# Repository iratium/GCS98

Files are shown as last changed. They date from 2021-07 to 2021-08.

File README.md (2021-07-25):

# GCS98
A collection of PCB and case designs for a modified 1800 layout I call GCS98.

modified_1800_v1_dark

I enjoy the flexibility of a full-size keyboard, but in my decade or so of using keyboards (including software for general home use, programming, gaming, and engineering work), I have never found a use for certain keys in and around the navigation cluster, namely Page Up, Page Down, Insert, Scroll Lock, Num Lock, and Pause Break. Additionally, the full size layout is not ergonomic in terms of gaming.

I discovered the 96% and 1800 layouts and felt I had discovered the perfect out-of-the-box solution in the 1800 layout specifically, but was disappointed to find that the layout is somewhat rare. My searches led me to the Keychron K4 (with this specific configuration https://www.keychron.com/products/keychron-k4-wireless-mechanical-keyboard-version-2?variant=32287344427097), and after substituting in Glorious Panda Switches for most keys and upgrading to PBT keys for the first time, I finally had a keyboard that felt like mine. Unfortunately, the K4 still has one major drawback being a compact 96% layout as opposed to a proper 1800: the remaining navigation keys, arrow keys, and delete key are not easily accessible by touch. 

To get the last 4% of customization that the compact 96% layout leaves in the aether, the only option forward is to do a fully custom build. I am a mechanical engineer by trade and I am familiar with the kinds of tools to design and manufacture a housed PCB; my specialty is not in electronics though, so I will inevitably be following tutorials and asking for help. 

Feel free to share this project with others, I've already been asked a couple of times whether I'd consider doing a group buy around this layout. You can also contact me over Discord Iratium#4718 or email at gavinshehan@gmail.com.

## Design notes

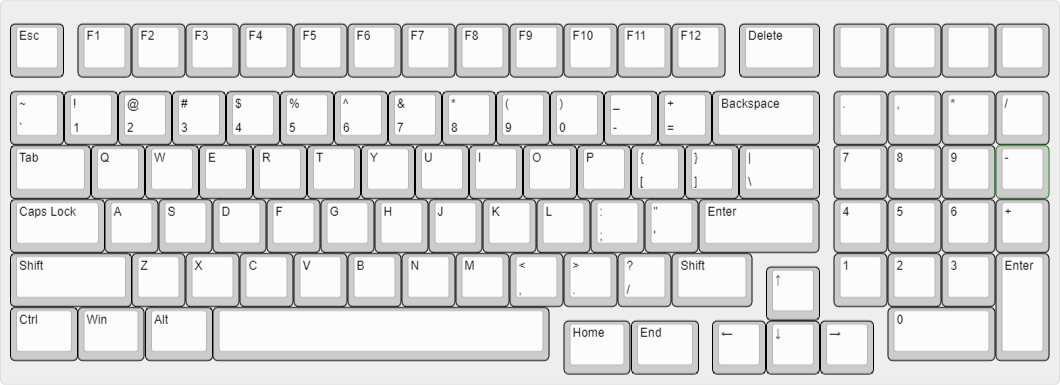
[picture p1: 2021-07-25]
GCS98.png

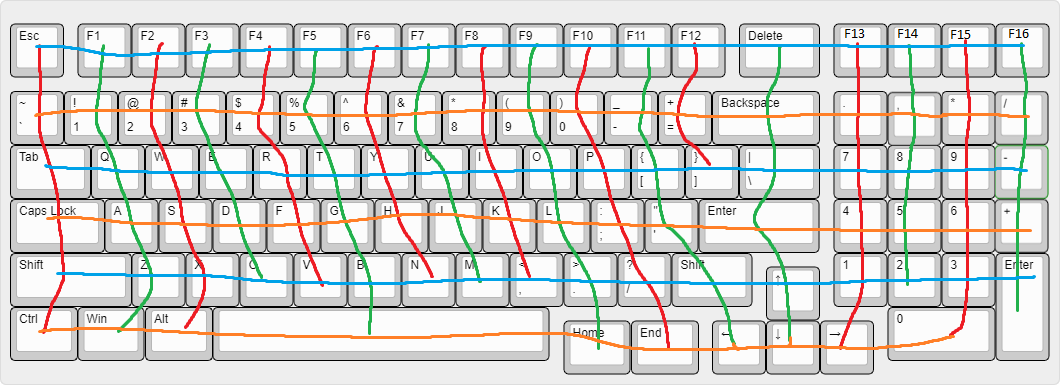
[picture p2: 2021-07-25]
GCS98 switch matrix.png

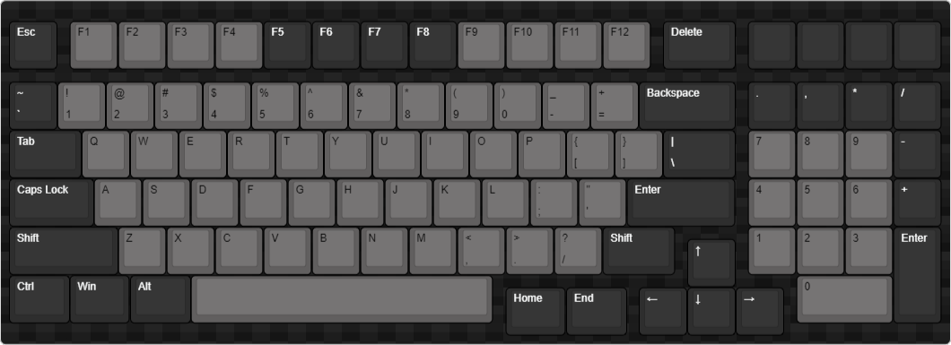
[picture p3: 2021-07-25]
GCS98_dark.png

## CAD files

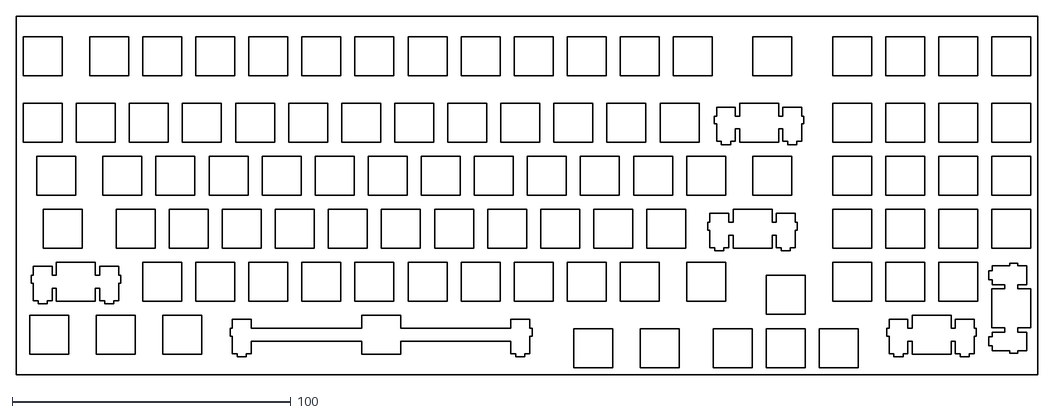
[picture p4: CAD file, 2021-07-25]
GCS98.dxf
366.7 x 128.6

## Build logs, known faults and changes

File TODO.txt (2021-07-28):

--------------------------------------------------------------------------------------
as of 2021-07-25:
--------------------------------------------------------------------------------------
GCS98v2
- find footprint for JST SH 4-pin connectors
- check to make sure it will work with the aio03-designed USB-C daughter board
- finalize outline of board to minimize space occupied outside of keycap footprint
- have someone verify board design for:
  * daughter board properly filters power rail/provides protection from ESD and other stuff
  * MCU is properly supplied with power and signal
  * MCU does actually have an internal oscillator and whether it will be sufficient
  * whether board has room for rgb to be added
  * overall design, whether it would function once assembled
        -> from here can fork off and work on v3 to add RGB
- start work toward midplate and case design:
  * manufacture (method and manufacturer)
  * materials
  * mounting method (gasket mounting ???)
  * modularity for loud/quiet versions (foam sheet, o-rings, rubber feet)
	
--------------------------------------------------------------------------------------
as of 2021-07-27:
--------------------------------------------------------------------------------------
GCS98v2
- check to make sure it will work with the aio03-designed USB-C daughter board
		= didn't verify 100% but it seems like it'll work
- finalize outline of board to minimize space occupied outside of keycap footprint
- have someone verify board design for:
		= should probably get a full design review before ordering parts if possible
  * daughter board properly filters power rail/provides protection from ESD and other stuff
		= pretty sure yea
  * MCU is properly supplied with power and signal
		= yup, but beware  pull-up resistor on D+
  * MCU does actually have an internal oscillator and whether it will be sufficient
		= internal resonator only for boot and low-speed operations, clock tends to vary
		widely with temperature; I am adding a crystal to the PCB
  * whether board has room for rgb to be added
		= yaes, check out sk6812 Mini-E RGB
  * overall design, whether it would function once assembled
        -> from here can fork off and work on v3 to add RGB
- start work toward midplate and case design:
  * manufacture (method and manufacturer)
  * materials
  * mounting method (gasket mounting ???)
  * modularity for loud/quiet versions (foam sheet, o-rings, rubber feet)

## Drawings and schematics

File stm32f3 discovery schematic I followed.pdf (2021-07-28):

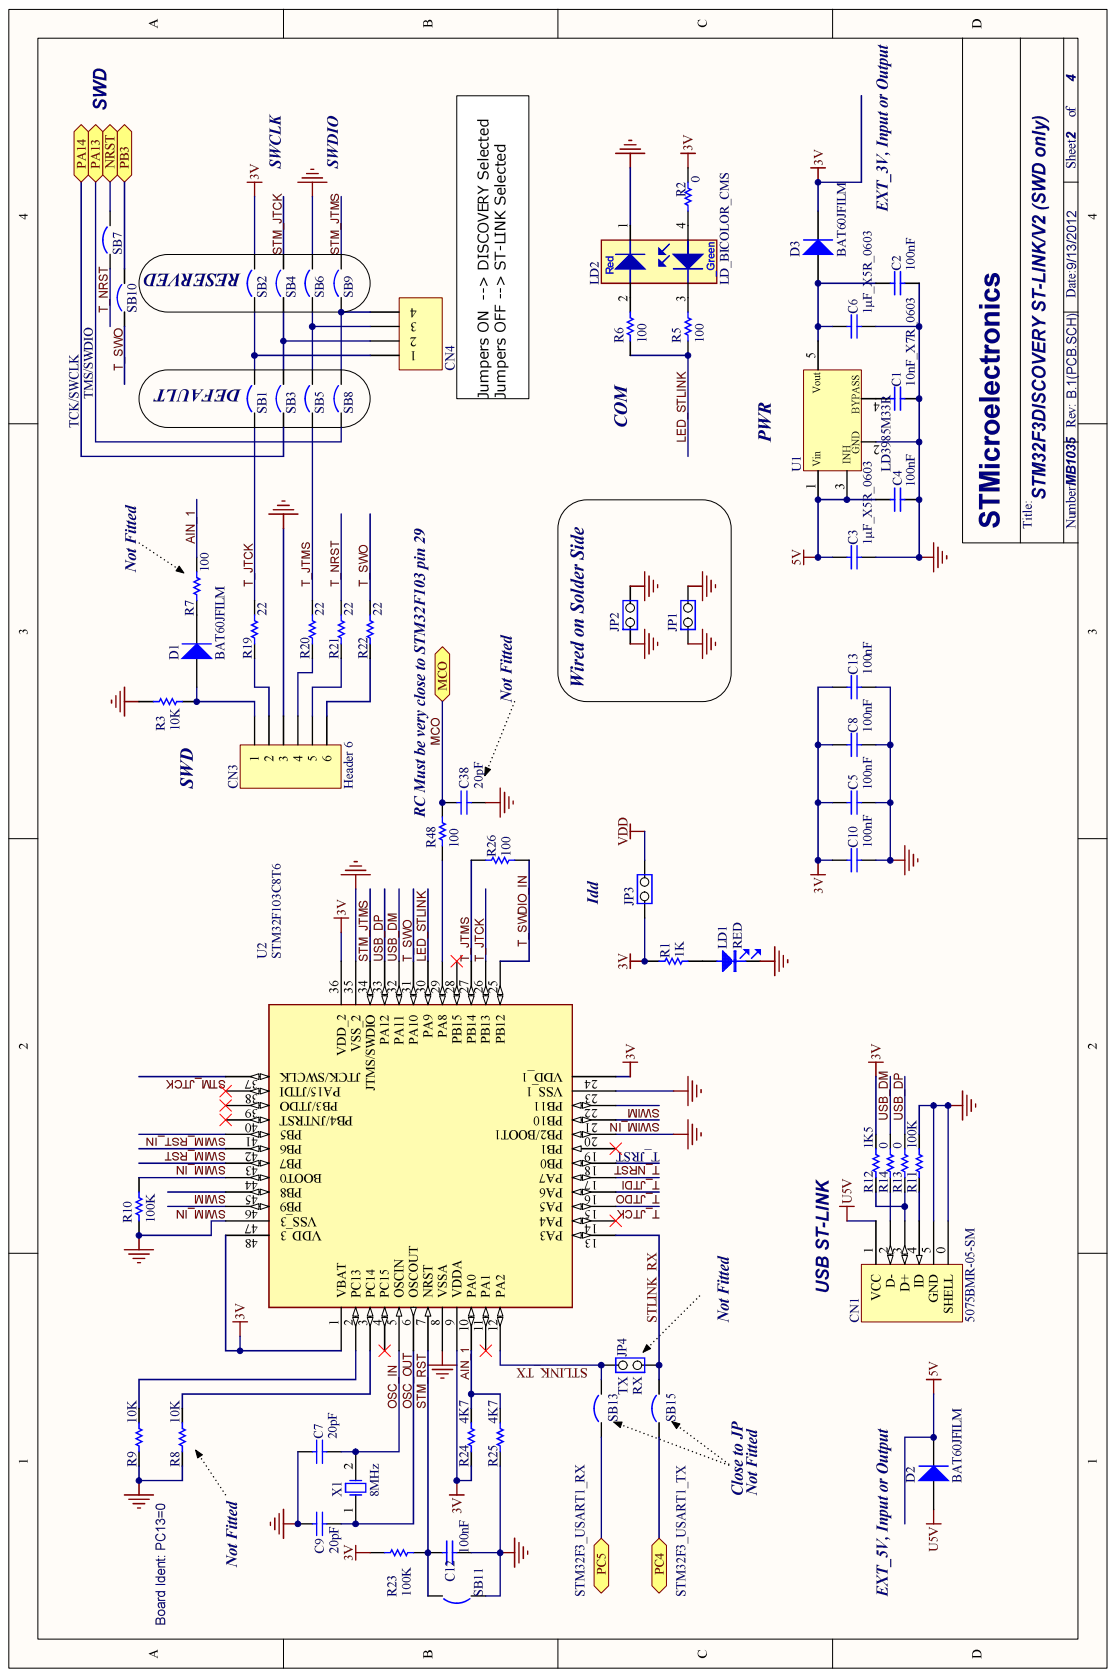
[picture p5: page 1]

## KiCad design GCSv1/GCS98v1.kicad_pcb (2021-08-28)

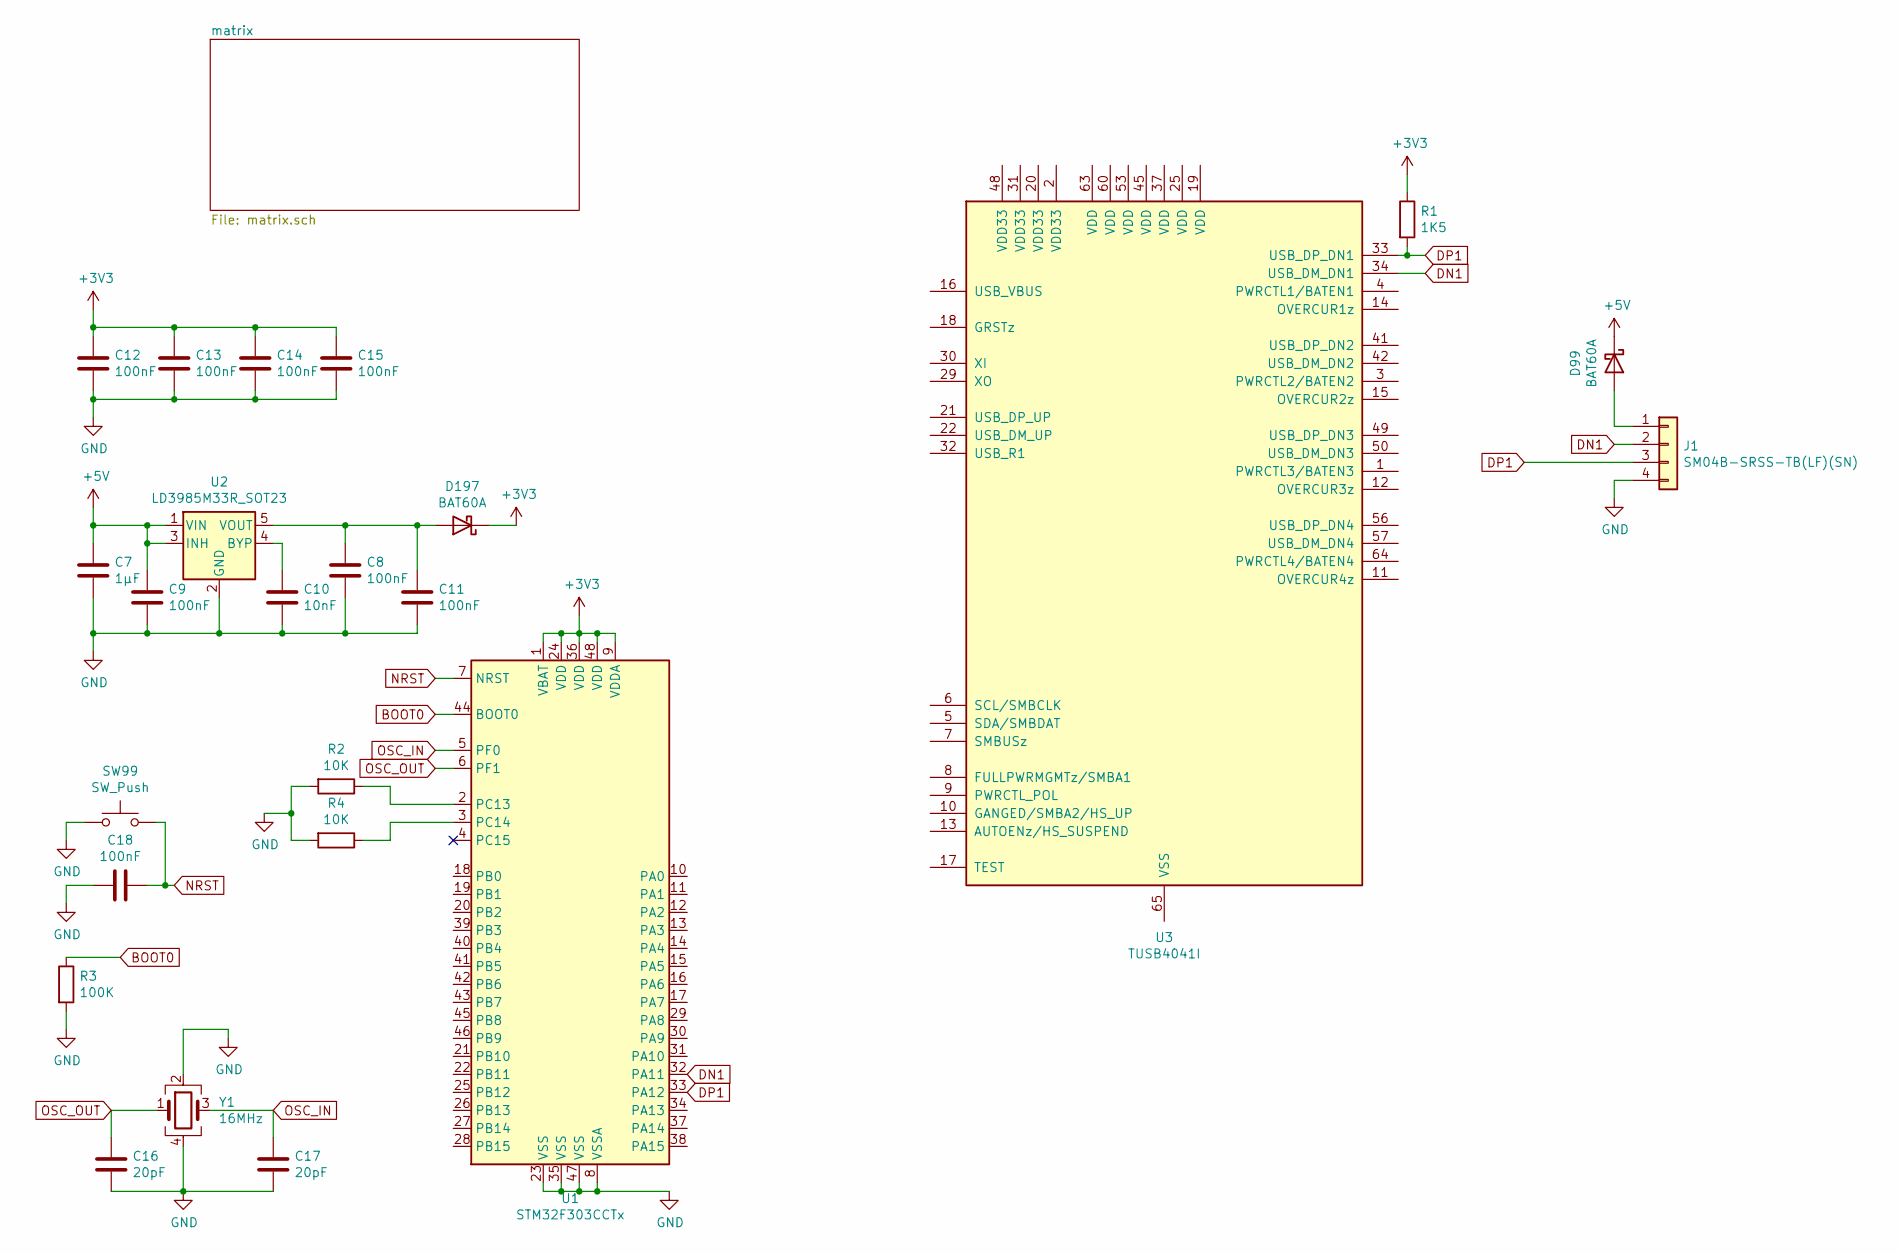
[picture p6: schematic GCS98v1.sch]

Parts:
C7: 1µF; C_0805_2012Metric_Pad1.18x1.45mm_HandSolder
C8, C9, C11, C12, C13, C14, C15, C18: 100nF; C_0805_2012Metric_Pad1.18x1.45mm_HandSolder
C10: 10nF; C_0805_2012Metric_Pad1.18x1.45mm_HandSolder
C16, C17: 20pF; C_0805_2012Metric_Pad1.18x1.45mm_HandSolder
D99, D197: BAT60A; D_SOD-323
J1: SM04B-SRSS-TB(LF)(SN); JST-SR-4
R1: 1K5; R_0805_2012Metric_Pad1.20x1.40mm_HandSolder
R2, R4: 10K; R_0805_2012Metric_Pad1.20x1.40mm_HandSolder
R3: 100K; R_0805_2012Metric_Pad1.20x1.40mm_HandSolder
SW99: SW_Push; SW_SPST_SKQG_WithStem
U1: STM32F303CCTx; LQFP-48_7x7mm_P0.5mm
U2: LD3985M33R_SOT23; SOT-23-5
U3: TUSB4041I; HTQFP-64-1EP_10x10mm_P0.5mm_EP8x8mm_Mask4.4x4.4mm_ThermalVi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
Y1: 16MHz; Crystal_SMD_3225-4Pin_3.2x2.5mm_HandSoldering

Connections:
+3V3: C12.1, C13.1, C14.1, C15.1, D197.1 (K), R1.1, U1.1 (VBAT), U1.9 (VDDA), U1.24 (VDD), U1.36 (VDD), U1.48 (VDD); also elsewhere on the board
+5V: C7.1, C9.1, D99.1 (K), U2.1 (VIN), U2.3 (INH); also elsewhere on the board
BOOT0: R3.1, U1.44 (BOOT0)
DN1: J1.2, U1.32 (PA11), U3.34 (USB_DM_DN1)
DP1: J1.3, R1.2, U1.33 (PA12), U3.33 (USB_DP_DN1)
GND: C7.2, C8.2, C9.2, C10.2, C11.2, C12.2, C13.2, C14.2, C15.2, C16.2, C17.2, C18.2, J1.4, R2.2, R3.2, R4.2, SW99.1, U1.8 (VSSA), U1.23 (VSS), U1.35 (VSS), U1.47 (VSS), U2.2 (GND), Y1.2, Y1.4; also elsewhere on the board
NRST: C18.1, SW99.2, U1.7 (NRST)
unnamed: C10.1, U2.4 (BYP)
unnamed: C8.1, C11.1, D197.2 (A), U2.5 (VOUT)
unnamed: D99.2 (A), J1.1
unnamed: R2.1, U1.2 (PC13)
unnamed: R4.1, U1.3 (PC14)
OSC_IN: C17.1, U1.5 (PF0), Y1.3
OSC_OUT: C16.1, U1.6 (PF1), Y1.1

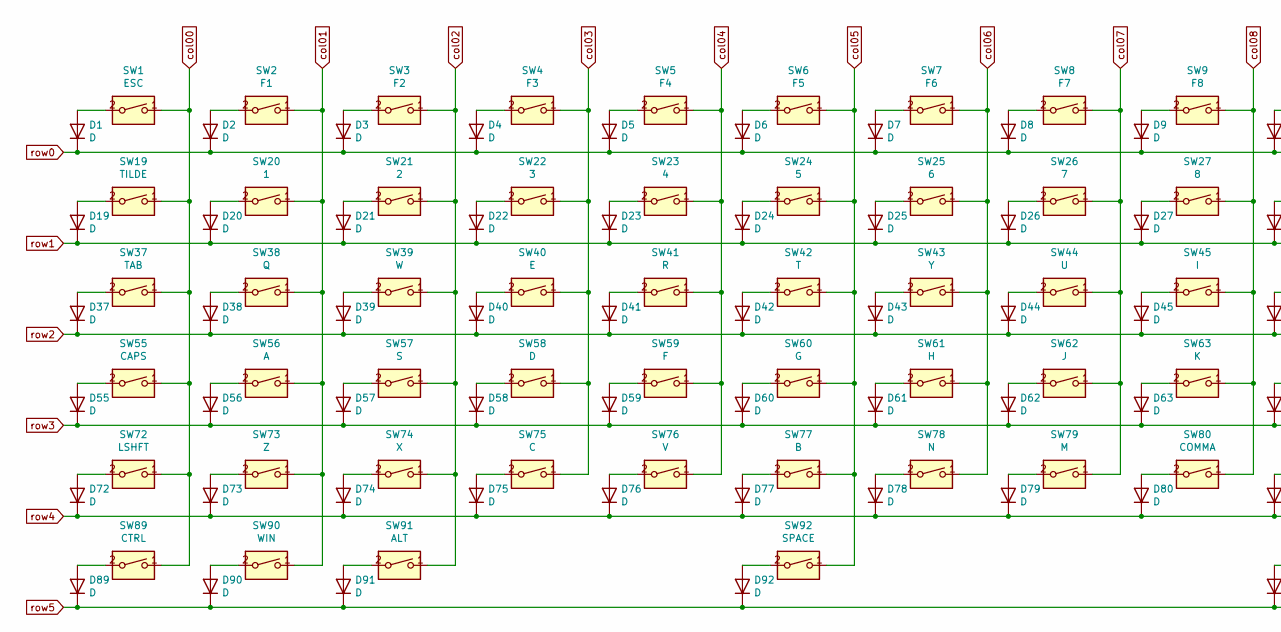
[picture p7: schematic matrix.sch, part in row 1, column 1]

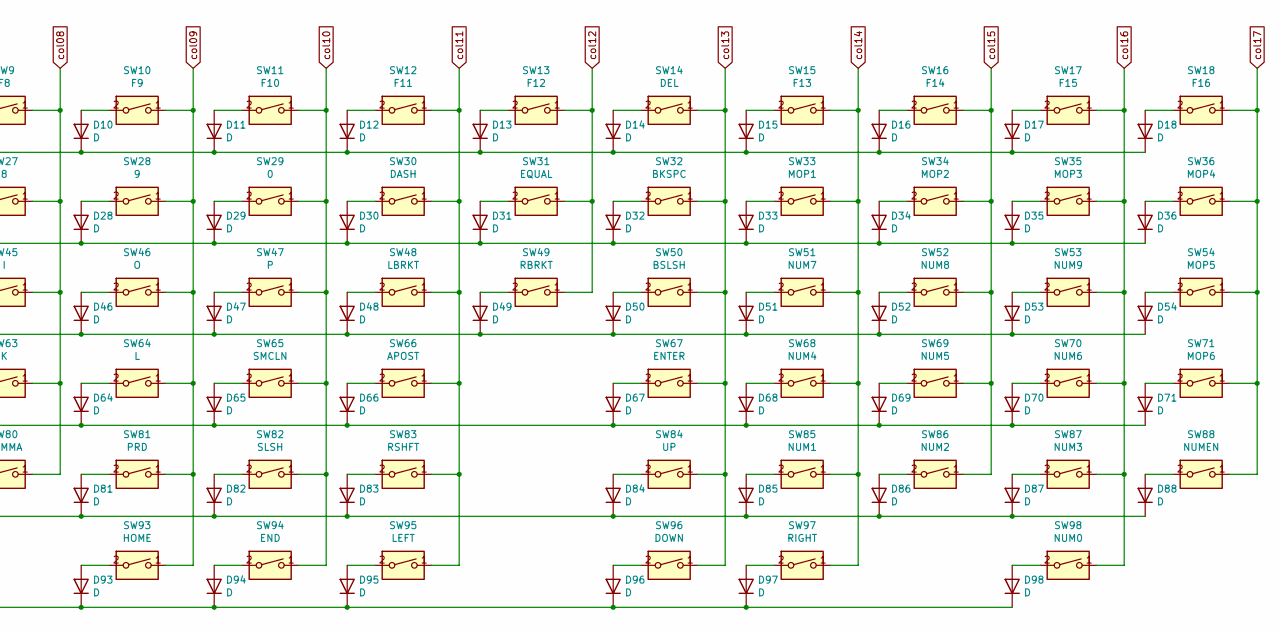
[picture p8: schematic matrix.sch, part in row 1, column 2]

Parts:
D1, D2, D3, D4, D5, D6, D7, D8, D9, D10, D11, D12, D13, D14, D15, D16, D17, D18, D19, D20, D21, D22, D23, D24, D25, D26, D27, D28, D29, D30, D31, D32, D33, D34, D35, D36, D37, D38, D39, D40, D41, D42, D43, D44, D45, D46, D47, D48, D49, D50, D51, D52, D53, D54, D55, D56, D57, D58, D59, D60, D61, D62, D63, D64, D65, D66, D67, D68, D69, D70, D71, D72, D73, D74, D75, D76, D77, D78, D79, D80, D81, D82, D83, D84, D85, D86, D87, D88, D89, D90, D91, D92, D93, D94, D95, D96, D97, D98: D; D_0805_2012Metric_Pad1.15x1.40mm_HandSolder
SW1: ESC; MX-1U-NoLED
SW2: F1; MX-1U-NoLED
SW3: F2; MX-1U-NoLED
SW4: F3; MX-1U-NoLED
SW5: F4; MX-1U-NoLED
SW6: F5; MX-1U-NoLED
SW7: F6; MX-1U-NoLED
SW8: F7; MX-1U-NoLED
SW9: F8; MX-1U-NoLED
SW10: F9; MX-1U-NoLED
SW11: F10; MX-1U-NoLED
SW12: F11; MX-1U-NoLED
SW13: F12; MX-1U-NoLED
SW14: DEL; MX-1.5U-NoLED
SW15: F13; MX-1U-NoLED
SW16: F14; MX-1U-NoLED
SW17: F15; MX-1U-NoLED
SW18: F16; MX-1U-NoLED
SW19: TILDE; MX-1U-NoLED
SW20: 1; MX-1U-NoLED
SW21: 2; MX-1U-NoLED
SW22: 3; MX-1U-NoLED
SW23: 4; MX-1U-NoLED
SW24: 5; MX-1U-NoLED
SW25: 6; MX-1U-NoLED
SW26: 7; MX-1U-NoLED
SW27: 8; MX-1U-NoLED
SW28: 9; MX-1U-NoLED
SW29: 0; MX-1U-NoLED
SW30: DASH; MX-1U-NoLED
SW31: EQUAL; MX-1U-NoLED
SW32: BKSPC; MX-2U-NoLED
SW33: MOP1; MX-1U-NoLED
SW34: MOP2; MX-1U-NoLED
SW35: MOP3; MX-1U-NoLED
SW36: MOP4; MX-1U-NoLED
SW37: TAB; MX-1.5U-NoLED
SW38: Q; MX-1U-NoLED
SW39: W; MX-1U-NoLED
SW40: E; MX-1U-NoLED
SW41: R; MX-1U-NoLED
SW42: T; MX-1U-NoLED
SW43: Y; MX-1U-NoLED
SW44: U; MX-1U-NoLED
SW45: I; MX-1U-NoLED
SW46: O; MX-1U-NoLED
SW47: P; MX-1U-NoLED
SW48: LBRKT; MX-1U-NoLED
SW49: RBRKT; MX-1U-NoLED
SW50: BSLSH; MX-1.5U-NoLED
SW51: NUM7; MX-1U-NoLED
SW52: NUM8; MX-1U-NoLED
SW53: NUM9; MX-1U-NoLED
SW54: MOP5; MX-1U-NoLED
SW55: CAPS; MX-1.75U-NoLED
SW56: A; MX-1U-NoLED
SW57: S; MX-1U-NoLED
SW58: D; MX-1U-NoLED
SW59: F; MX-1U-NoLED
SW60: G; MX-1U-NoLED
SW61: H; MX-1U-NoLED
SW62: J; MX-1U-NoLED
SW63: K; MX-1U-NoLED
SW64: L; MX-1U-NoLED
SW65: SMCLN; MX-1U-NoLED
SW66: APOST; MX-1U-NoLED
SW67: ENTER; MX-2.25U-NoLED
SW68: NUM4; MX-1U-NoLED
SW69: NUM5; MX-1U-NoLED
SW70: NUM6; MX-1U-NoLED
SW71: MOP6; MX-1U-NoLED
SW72: LSHFT; MX-2.25U-NoLED
SW73: Z; MX-1U-NoLED
SW74: X; MX-1U-NoLED
SW75: C; MX-1U-NoLED
SW76: V; MX-1U-NoLED
SW77: B; MX-1U-NoLED
SW78: N; MX-1U-NoLED
SW79: M; MX-1U-NoLED
SW80: COMMA; MX-1U-NoLED
SW81: PRD; MX-1U-NoLED
SW82: SLSH; MX-1U-NoLED
SW83: RSHFT; MX-1.5U-NoLED
SW84: UP; MX-1U-NoLED
SW85: NUM1; MX-1U-NoLED
SW86: NUM2; MX-1U-NoLED
SW87: NUM3; MX-1U-NoLED
SW88: NUMEN; MX-2U-NoLED
SW89: CTRL; MX-1.25U-NoLED
SW90: WIN; MX-1.25U-NoLED
SW91: ALT; MX-1.25U-NoLED
SW92: SPACE; MX-6.25U-NoLED
SW93: HOME; MX-1.25U-NoLED
SW94: END; MX-1.25U-NoLED
SW95: LEFT; MX-1U-NoLED
SW96: DOWN; MX-1U-NoLED
SW97: RIGHT; MX-1U-NoLED
SW98: NUM0; MX-2U-NoLED

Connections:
unnamed: D1.2 (A), SW1.2
unnamed: D2.2 (A), SW2.2
unnamed: D3.2 (A), SW3.2
unnamed: D4.2 (A), SW4.2
unnamed: D5.2 (A), SW5.2
unnamed: D6.2 (A), SW6.2
unnamed: D7.2 (A), SW7.2
unnamed: D8.2 (A), SW8.2
unnamed: D9.2 (A), SW9.2
unnamed: D10.2 (A), SW10.2
unnamed: D11.2 (A), SW11.2
unnamed: D12.2 (A), SW12.2
unnamed: D13.2 (A), SW13.2
unnamed: D14.2 (A), SW14.2
unnamed: D15.2 (A), SW15.2
unnamed: D16.2 (A), SW16.2
unnamed: D17.2 (A), SW17.2
unnamed: D18.2 (A), SW18.2
unnamed: D19.2 (A), SW19.2
unnamed: D20.2 (A), SW20.2
unnamed: D21.2 (A), SW21.2
unnamed: D22.2 (A), SW22.2
unnamed: D23.2 (A), SW23.2
unnamed: D24.2 (A), SW24.2
unnamed: D25.2 (A), SW25.2
unnamed: D26.2 (A), SW26.2
unnamed: D27.2 (A), SW27.2
unnamed: D28.2 (A), SW28.2
unnamed: D29.2 (A), SW29.2
unnamed: D30.2 (A), SW30.2
unnamed: D31.2 (A), SW31.2
unnamed: D32.2 (A), SW32.2
unnamed: D33.2 (A), SW33.2
unnamed: D34.2 (A), SW34.2
unnamed: D35.2 (A), SW35.2
unnamed: D36.2 (A), SW36.2
unnamed: D37.2 (A), SW37.2
unnamed: D38.2 (A), SW38.2
unnamed: D39.2 (A), SW39.2
unnamed: D40.2 (A), SW40.2
unnamed: D41.2 (A), SW41.2
unnamed: D42.2 (A), SW42.2
unnamed: D43.2 (A), SW43.2
unnamed: D44.2 (A), SW44.2
unnamed: D45.2 (A), SW45.2
unnamed: D46.2 (A), SW46.2
unnamed: D47.2 (A), SW47.2
unnamed: D48.2 (A), SW48.2
unnamed: D49.2 (A), SW49.2
unnamed: D50.2 (A), SW50.2
unnamed: D51.2 (A), SW51.2
unnamed: D52.2 (A), SW52.2
unnamed: D53.2 (A), SW53.2
unnamed: D54.2 (A), SW54.2
unnamed: D55.2 (A), SW55.2
unnamed: D56.2 (A), SW56.2
unnamed: D57.2 (A), SW57.2
unnamed: D58.2 (A), SW58.2
unnamed: D59.2 (A), SW59.2
unnamed: D60.2 (A), SW60.2
unnamed: D61.2 (A), SW61.2
unnamed: D62.2 (A), SW62.2
unnamed: D63.2 (A), SW63.2
unnamed: D64.2 (A), SW64.2
unnamed: D65.2 (A), SW65.2
unnamed: D66.2 (A), SW66.2
unnamed: D67.2 (A), SW67.2
unnamed: D68.2 (A), SW68.2
unnamed: D69.2 (A), SW69.2
unnamed: D70.2 (A), SW70.2
unnamed: D71.2 (A), SW71.2
unnamed: D72.2 (A), SW72.2
unnamed: D73.2 (A), SW73.2
unnamed: D74.2 (A), SW74.2
unnamed: D75.2 (A), SW75.2
unnamed: D76.2 (A), SW76.2
unnamed: D77.2 (A), SW77.2
unnamed: D78.2 (A), SW78.2
unnamed: D79.2 (A), SW79.2
unnamed: D80.2 (A), SW80.2
unnamed: D81.2 (A), SW81.2
unnamed: D82.2 (A), SW82.2
unnamed: D83.2 (A), SW83.2
unnamed: D84.2 (A), SW84.2
unnamed: D85.2 (A), SW85.2
unnamed: D86.2 (A), SW86.2
unnamed: D87.2 (A), SW87.2
unnamed: D88.2 (A), SW88.2
unnamed: D89.2 (A), SW89.2
unnamed: D90.2 (A), SW90.2
unnamed: D91.2 (A), SW91.2
unnamed: D92.2 (A), SW92.2
unnamed: D93.2 (A), SW93.2
unnamed: D94.2 (A), SW94.2
unnamed: D95.2 (A), SW95.2
unnamed: D96.2 (A), SW96.2
unnamed: D97.2 (A), SW97.2
unnamed: D98.2 (A), SW98.2
col00: SW1.1, SW19.1, SW37.1, SW55.1, SW72.1, SW89.1
col01: SW2.1, SW20.1, SW38.1, SW56.1, SW73.1, SW90.1
col02: SW3.1, SW21.1, SW39.1, SW57.1, SW74.1, SW91.1
col03: SW4.1, SW22.1, SW40.1, SW58.1, SW75.1
col04: SW5.1, SW23.1, SW41.1, SW59.1, SW76.1
col05: SW6.1, SW24.1, SW42.1, SW60.1, SW77.1, SW92.1
col06: SW7.1, SW25.1, SW43.1, SW61.1, SW78.1
col07: SW8.1, SW26.1, SW44.1, SW62.1, SW79.1
col08: SW9.1, SW27.1, SW45.1, SW63.1, SW80.1
col09: SW10.1, SW28.1, SW46.1, SW64.1, SW81.1, SW93.1
col10: SW11.1, SW29.1, SW47.1, SW65.1, SW82.1, SW94.1
col11: SW12.1, SW30.1, SW48.1, SW66.1, SW83.1, SW95.1
col12: SW13.1, SW31.1, SW49.1
col13: SW14.1, SW32.1, SW50.1, SW67.1, SW84.1, SW96.1
col14: SW15.1, SW33.1, SW51.1, SW68.1, SW85.1, SW97.1
col15: SW16.1, SW34.1, SW52.1, SW69.1, SW86.1
col16: SW17.1, SW35.1, SW53.1, SW70.1, SW87.1, SW98.1
col17: SW18.1, SW36.1, SW54.1, SW71.1, SW88.1
row0: D1.1 (K), D2.1 (K), D3.1 (K), D4.1 (K), D5.1 (K), D6.1 (K), D7.1 (K), D8.1 (K), D9.1 (K), D10.1 (K), D11.1 (K), D12.1 (K), D13.1 (K), D14.1 (K), D15.1 (K), D16.1 (K), D17.1 (K), D18.1 (K)
row1: D19.1 (K), D20.1 (K), D21.1 (K), D22.1 (K), D23.1 (K), D24.1 (K), D25.1 (K), D26.1 (K), D27.1 (K), D28.1 (K), D29.1 (K), D30.1 (K), D31.1 (K), D32.1 (K), D33.1 (K), D34.1 (K), D35.1 (K), D36.1 (K)
row2: D37.1 (K), D38.1 (K), D39.1 (K), D40.1 (K), D41.1 (K), D42.1 (K), D43.1 (K), D44.1 (K), D45.1 (K), D46.1 (K), D47.1 (K), D48.1 (K), D49.1 (K), D50.1 (K), D51.1 (K), D52.1 (K), D53.1 (K), D54.1 (K)
row3: D55.1 (K), D56.1 (K), D57.1 (K), D58.1 (K), D59.1 (K), D60.1 (K), D61.1 (K), D62.1 (K), D63.1 (K), D64.1 (K), D65.1 (K), D66.1 (K), D67.1 (K), D68.1 (K), D69.1 (K), D70.1 (K), D71.1 (K)
row4: D72.1 (K), D73.1 (K), D74.1 (K), D75.1 (K), D76.1 (K), D77.1 (K), D78.1 (K), D79.1 (K), D80.1 (K), D81.1 (K), D82.1 (K), D83.1 (K), D84.1 (K), D85.1 (K), D86.1 (K), D87.1 (K), D88.1 (K)
row5: D89.1 (K), D90.1 (K), D91.1 (K), D92.1 (K), D93.1 (K), D94.1 (K), D95.1 (K), D96.1 (K), D97.1 (K), D98.1 (K)

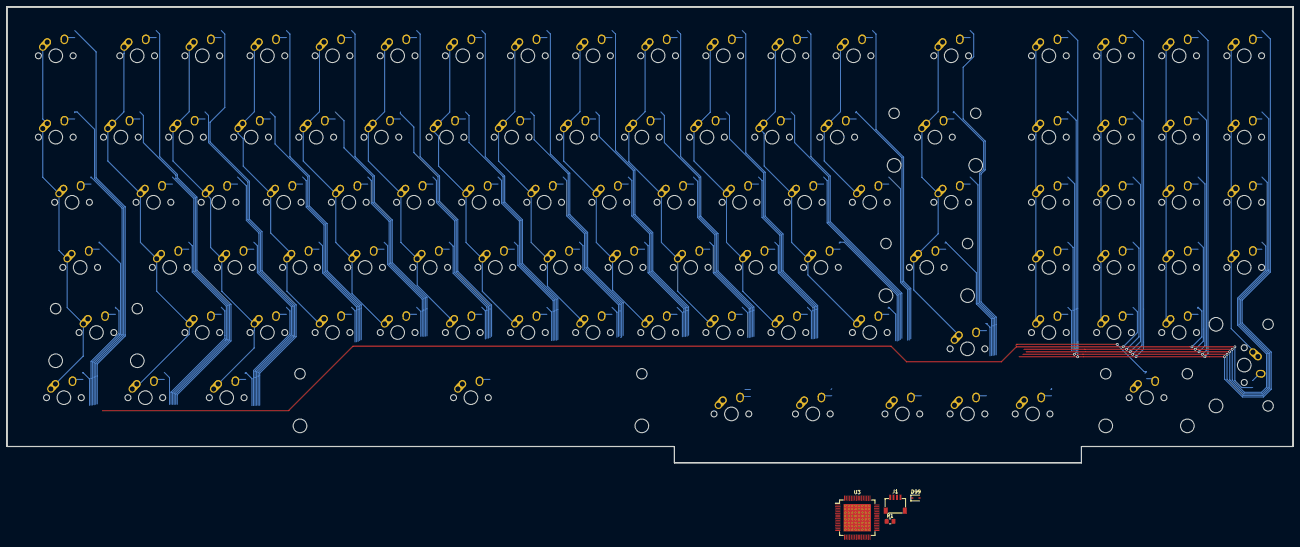
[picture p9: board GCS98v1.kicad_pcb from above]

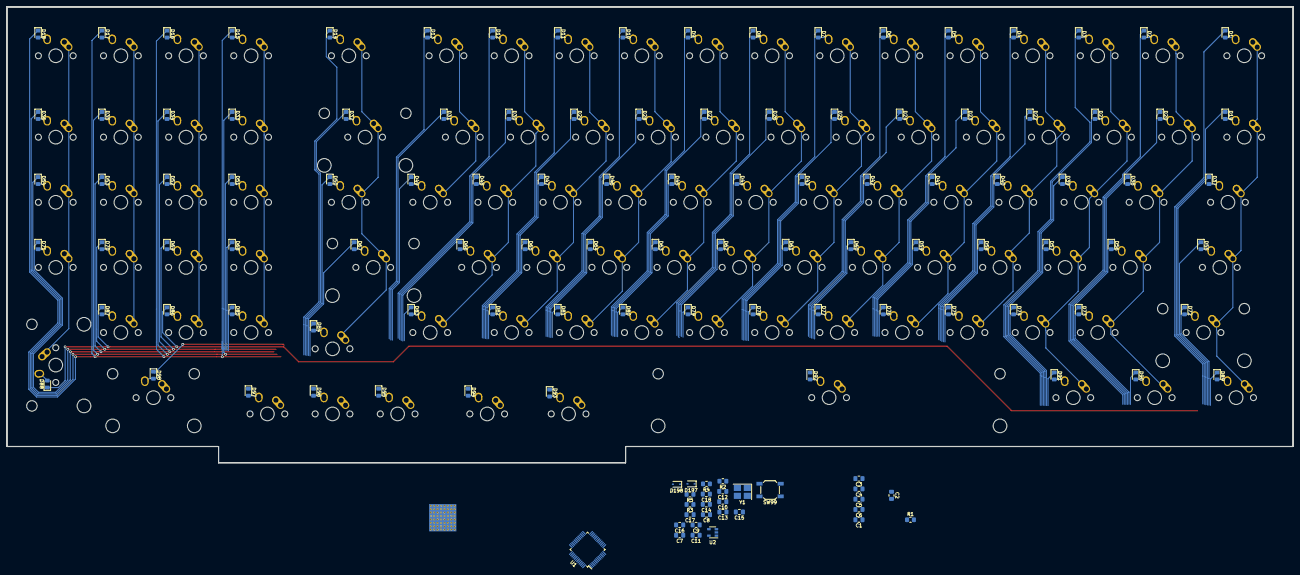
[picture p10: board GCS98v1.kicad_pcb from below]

Board: 2 copper layers, 376.2 x 133.3 mm, 229 parts (127 on the bottom side), 136 nets.

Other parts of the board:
C1, C2, C3, C4, C5, C6: 100µF; C_0805_2012Metric_Pad1.18x1.45mm_HandSolder
D198: BAT60A; D_SOD-323
R1#2: 0.5K; R_0805_2012Metric_Pad1.20x1.40mm_HandSolder
R5: 1K5; R_0805_2012Metric_Pad1.20x1.40mm_HandSolder

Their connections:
+3V3: R5.1; also elsewhere on the board
+5V: C1.1, C2.1, C3.1, C4.1, C5.1, C6.1, D198.1; also elsewhere on the board
GND: C1.2, C2.2, C3.2, C4.2, C5.2, C6.2; also elsewhere on the board

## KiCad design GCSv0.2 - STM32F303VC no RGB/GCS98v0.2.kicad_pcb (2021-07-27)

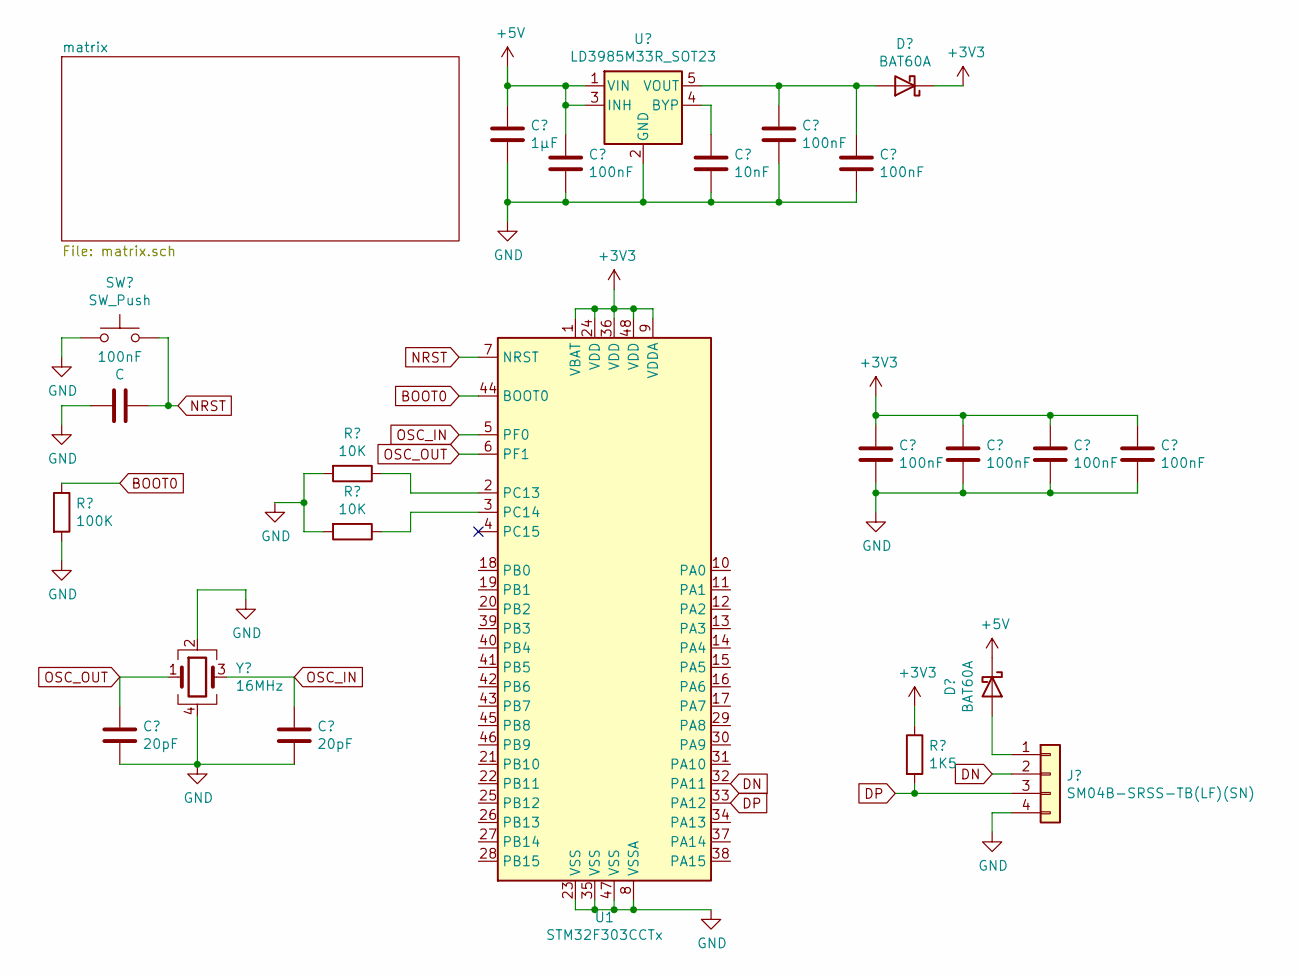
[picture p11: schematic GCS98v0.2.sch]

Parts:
100nF: C
U1: STM32F303CCTx; LQFP-48_7x7mm_P0.5mm

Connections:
+5V: U1.1 (VBAT), U1.9 (VDDA), U1.24 (VDD), U1.36 (VDD), U1.48 (VDD); also elsewhere on the board
GND: 100nF.2, U1.8 (VSSA), U1.23 (VSS), U1.35 (VSS), U1.47 (VSS); also elsewhere on the board
unnamed 2: 100nF.1, U1.7 (NRST); also elsewhere on the board
unnamed 103: U1.44 (BOOT0); also elsewhere on the board

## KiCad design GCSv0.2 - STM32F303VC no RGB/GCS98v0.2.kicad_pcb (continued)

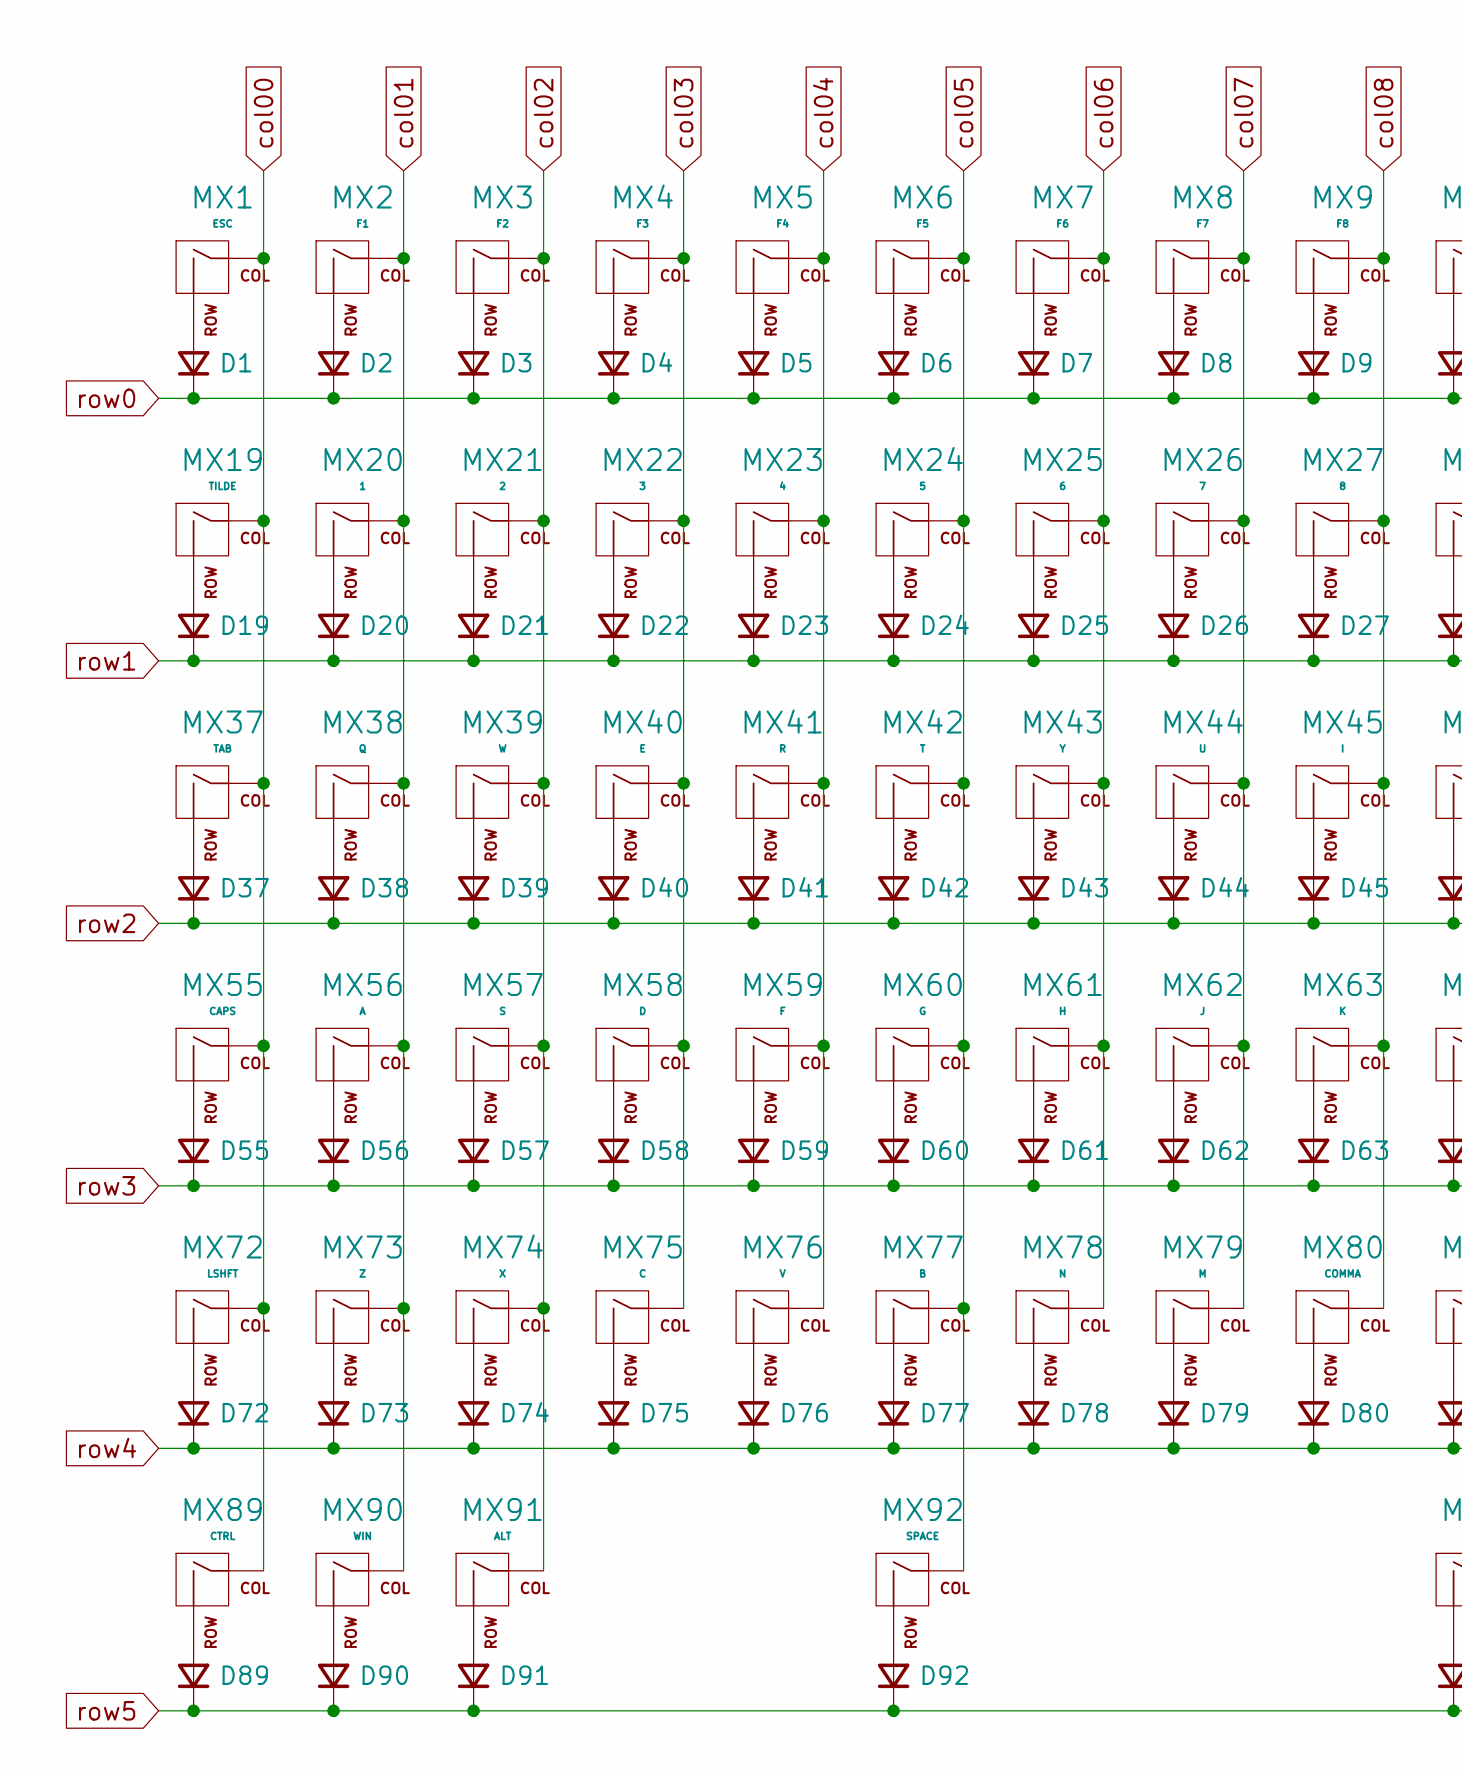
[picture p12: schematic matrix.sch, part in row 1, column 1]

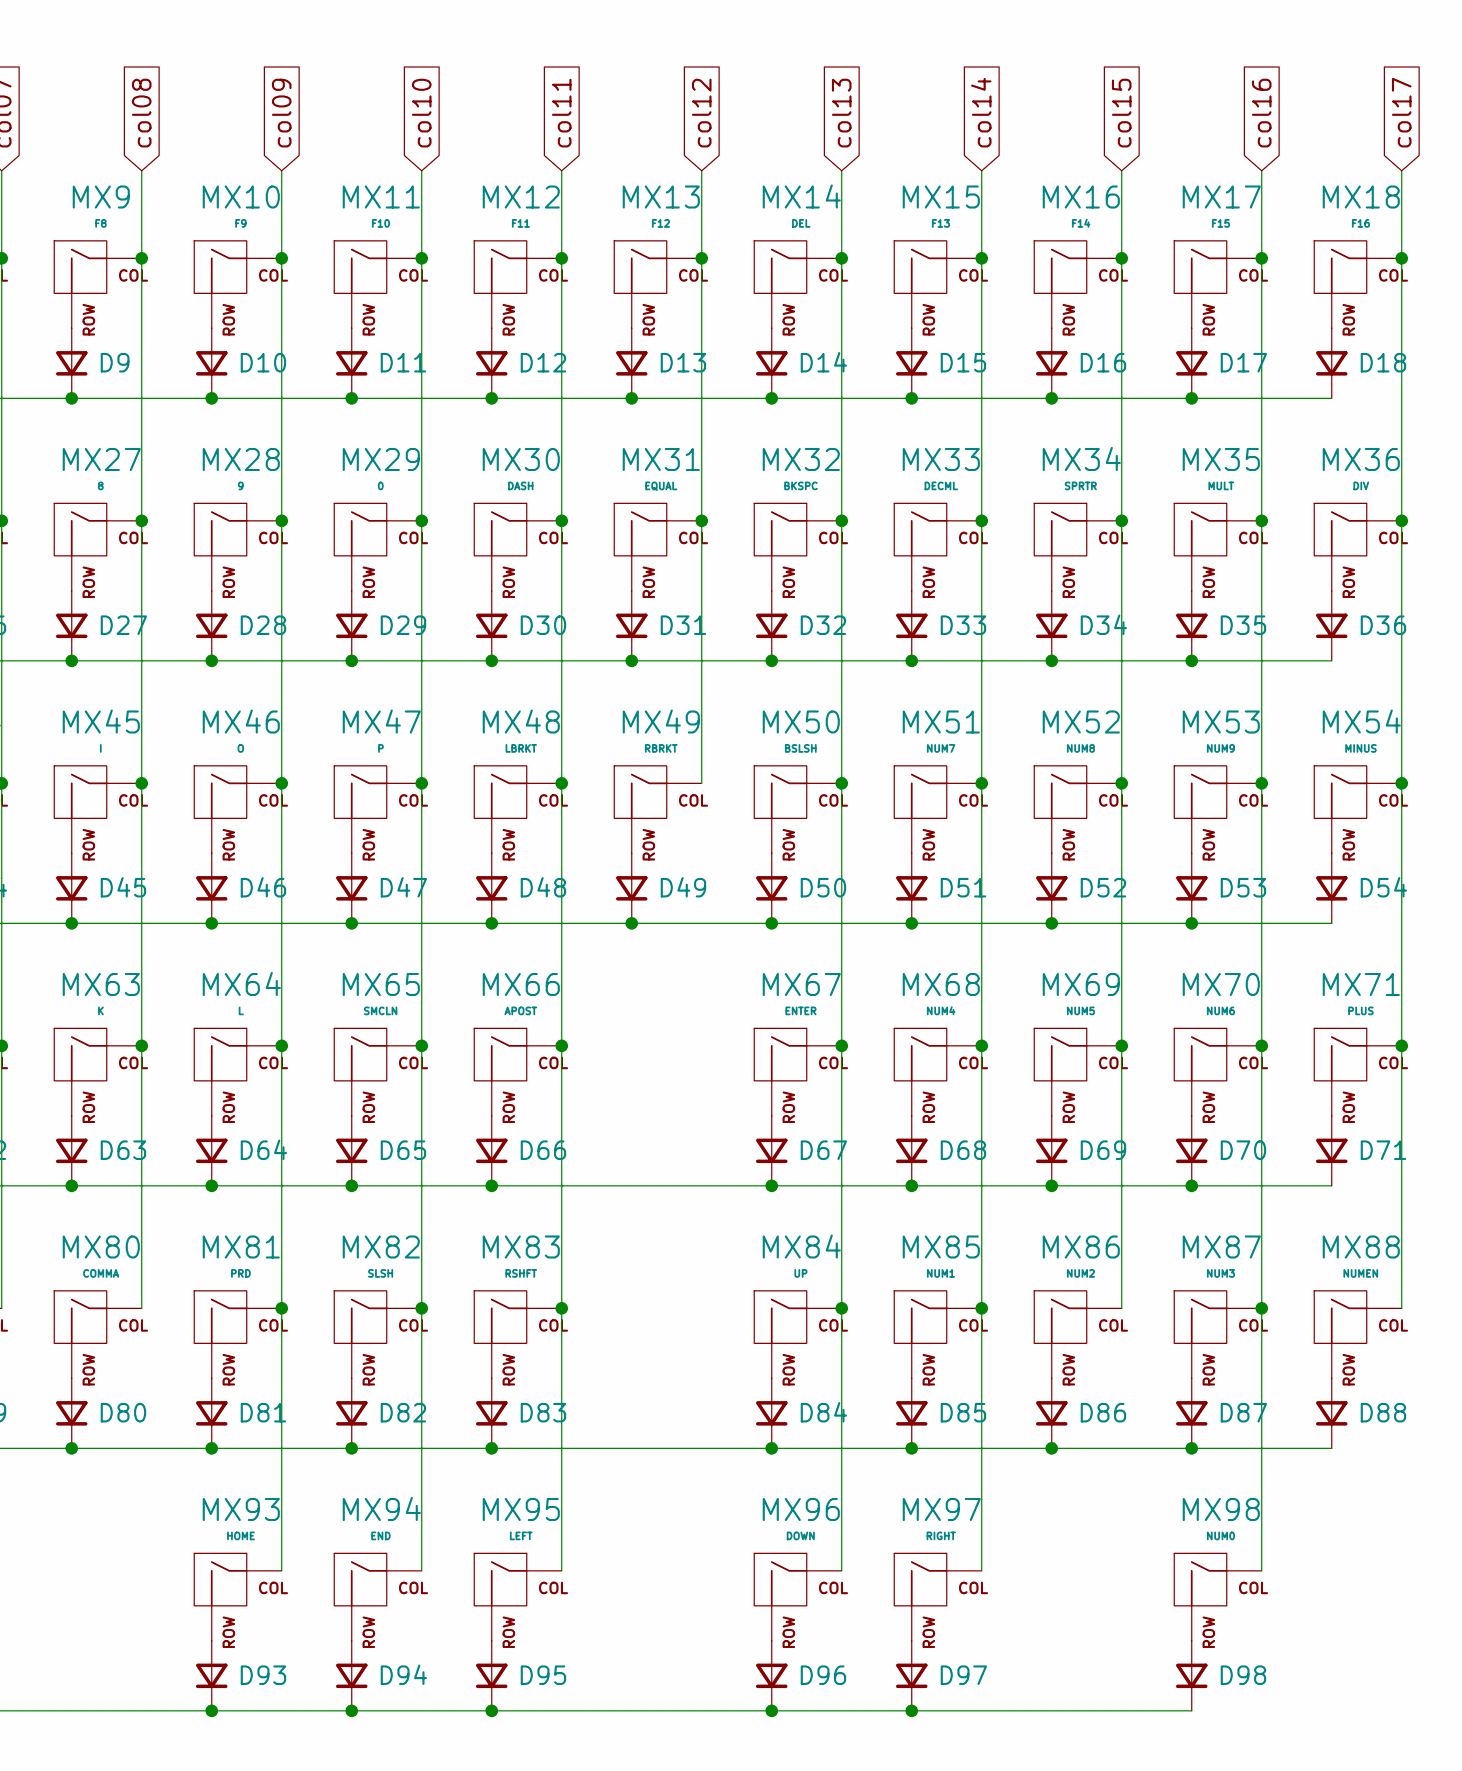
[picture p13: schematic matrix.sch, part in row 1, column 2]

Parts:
D1, D2, D3, D4, D5, D6, D7, D8, D9, D10, D11, D12, D13, D14, D15, D16, D17, D18, D19, D20, D21, D22, D23, D24, D25, D26, D27, D28, D29, D30, D31, D32, D33, D34, D35, D36, D37, D38, D39, D40, D41, D42, D43, D44, D45, D46, D47, D48, D49, D50, D51, D52, D53, D54, D55, D56, D57, D58, D59, D60, D61, D62, D63, D64, D65, D66, D67, D68, D69, D70, D71, D72, D73, D74, D75, D76, D77, D78, D79, D80, D81, D82, D83, D84, D85, D86, D87, D88, D89, D90, D91, D92, D93, D94, D95, D96, D97, D98: D_Small; D_SOD-123
MX1: ESC; MX-1U-NoLED
MX2: F1; MX-1U-NoLED
MX3: F2; MX-1U-NoLED
MX4: F3; MX-1U-NoLED
MX5: F4; MX-1U-NoLED
MX6: F5; MX-1U-NoLED
MX7: F6; MX-1U-NoLED
MX8: F7; MX-1U-NoLED
MX9: F8; MX-1U-NoLED
MX10: F9; MX-1U-NoLED
MX11: F10; MX-1U-NoLED
MX12: F11; MX-1U-NoLED
MX13: F12; MX-1U-NoLED
MX14: DEL; MX-1.5U-NoLED
MX15: F13; MX-1U-NoLED
MX16: F14; MX-1U-NoLED
MX17: F15; MX-1U-NoLED
MX18: F16; MX-1U-NoLED
MX19: TILDE; MX-1U-NoLED
MX20: 1; MX-1U-NoLED
MX21: 2; MX-1U-NoLED
MX22: 3; MX-1U-NoLED
MX23: 4; MX-1U-NoLED
MX24: 5; MX-1U-NoLED
MX25: 6; MX-1U-NoLED
MX26: 7; MX-1U-NoLED
MX27: 8; MX-1U-NoLED
MX28: 9; MX-1U-NoLED
MX29: 0; MX-1U-NoLED
MX30: DASH; MX-1U-NoLED
MX31: EQUAL; MX-1U-NoLED
MX32: BKSPC; MX-2U-NoLED
MX33: DECML; MX-1U-NoLED
MX34: SPRTR; MX-1U-NoLED
MX35: MULT; MX-1U-NoLED
MX36: DIV; MX-1U-NoLED
MX37: TAB; MX-1.5U-NoLED
MX38: Q; MX-1U-NoLED
MX39: W; MX-1U-NoLED
MX40: E; MX-1U-NoLED
MX41: R; MX-1U-NoLED
MX42: T; MX-1U-NoLED
MX43: Y; MX-1U-NoLED
MX44: U; MX-1U-NoLED
MX45: I; MX-1U-NoLED
MX46: O; MX-1U-NoLED
MX47: P; MX-1U-NoLED
MX48: LBRKT; MX-1U-NoLED
MX49: RBRKT; MX-1U-NoLED
MX50: BSLSH; MX-1.5U-NoLED
MX51: NUM7; MX-1U-NoLED
MX52: NUM8; MX-1U-NoLED
MX53: NUM9; MX-1U-NoLED
MX54: MINUS; MX-1U-NoLED
MX55: CAPS; MX-1.75U-NoLED
MX56: A; MX-1U-NoLED
MX57: S; MX-1U-NoLED
MX58: D; MX-1U-NoLED
MX59: F; MX-1U-NoLED
MX60: G; MX-1U-NoLED
MX61: H; MX-1U-NoLED
MX62: J; MX-1U-NoLED
MX63: K; MX-1U-NoLED
MX64: L; MX-1U-NoLED
MX65: SMCLN; MX-1U-NoLED
MX66: APOST; MX-1U-NoLED
MX67: ENTER; MX-2.25U-NoLED
MX68: NUM4; MX-1U-NoLED
MX69: NUM5; MX-1U-NoLED
MX70: NUM6; MX-1U-NoLED
MX71: PLUS; MX-1U-NoLED
MX72: LSHFT; MX-2.25U-NoLED
MX73: Z; MX-1U-NoLED
MX74: X; MX-1U-NoLED
MX75: C; MX-1U-NoLED
MX76: V; MX-1U-NoLED
MX77: B; MX-1U-NoLED
MX78: N; MX-1U-NoLED
MX79: M; MX-1U-NoLED
MX80: COMMA; MX-1U-NoLED
MX81: PRD; MX-1U-NoLED
MX82: SLSH; MX-1U-NoLED
MX83: RSHFT; MX-1.5U-NoLED
MX84: UP; MX-1U-NoLED
MX85: NUM1; MX-1U-NoLED
MX86: NUM2; MX-1U-NoLED
MX87: NUM3; MX-1U-NoLED
MX88: NUMEN; MX-2U-NoLED
MX89: CTRL; MX-1.25U-NoLED
MX90: WIN; MX-1.25U-NoLED
MX91: ALT; MX-1.25U-NoLED
MX92: SPACE; MX-6.25U-NoLED
MX93: HOME; MX-1.25U-NoLED
MX94: END; MX-1.25U-NoLED
MX95: LEFT; MX-1U-NoLED
MX96: DOWN; MX-1U-NoLED
MX97: RIGHT; MX-1U-NoLED
MX98: NUM0; MX-2U-NoLED

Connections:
unnamed: D1.2 (A), MX1.2 (ROW)
unnamed: D2.2 (A), MX2.2 (ROW)
unnamed: D3.2 (A), MX3.2 (ROW)
unnamed: D4.2 (A), MX4.2 (ROW)
unnamed: D5.2 (A), MX5.2 (ROW)
unnamed: D6.2 (A), MX6.2 (ROW)
unnamed: D7.2 (A), MX7.2 (ROW)
unnamed: D8.2 (A), MX8.2 (ROW)
unnamed: D9.2 (A), MX9.2 (ROW)
unnamed: D10.2 (A), MX10.2 (ROW)
unnamed: D11.2 (A), MX11.2 (ROW)
unnamed: D12.2 (A), MX12.2 (ROW)
unnamed: D13.2 (A), MX13.2 (ROW)
unnamed: D14.2 (A), MX14.2 (ROW)
unnamed: D15.2 (A), MX15.2 (ROW)
unnamed: D16.2 (A), MX16.2 (ROW)
unnamed: D17.2 (A), MX17.2 (ROW)
unnamed: D18.2 (A), MX18.2 (ROW)
unnamed: D19.2 (A), MX19.2 (ROW)
unnamed: D20.2 (A), MX20.2 (ROW)
unnamed: D21.2 (A), MX21.2 (ROW)
unnamed: D22.2 (A), MX22.2 (ROW)
unnamed: D23.2 (A), MX23.2 (ROW)
unnamed: D24.2 (A), MX24.2 (ROW)
unnamed: D25.2 (A), MX25.2 (ROW)
unnamed: D26.2 (A), MX26.2 (ROW)
unnamed: D27.2 (A), MX27.2 (ROW)
unnamed: D28.2 (A), MX28.2 (ROW)
unnamed: D29.2 (A), MX29.2 (ROW)
unnamed: D30.2 (A), MX30.2 (ROW)
unnamed: D31.2 (A), MX31.2 (ROW)
unnamed: D32.2 (A), MX32.2 (ROW)
unnamed: D33.2 (A), MX33.2 (ROW)
unnamed: D34.2 (A), MX34.2 (ROW)
unnamed: D35.2 (A), MX35.2 (ROW)
unnamed: D36.2 (A), MX36.2 (ROW)
unnamed: D37.2 (A), MX37.2 (ROW)
unnamed: D38.2 (A), MX38.2 (ROW)
unnamed: D39.2 (A), MX39.2 (ROW)
unnamed: D40.2 (A), MX40.2 (ROW)
unnamed: D41.2 (A), MX41.2 (ROW)
unnamed: D42.2 (A), MX42.2 (ROW)
unnamed: D43.2 (A), MX43.2 (ROW)
unnamed: D44.2 (A), MX44.2 (ROW)
unnamed: D45.2 (A), MX45.2 (ROW)
unnamed: D46.2 (A), MX46.2 (ROW)
unnamed: D47.2 (A), MX47.2 (ROW)
unnamed: D48.2 (A), MX48.2 (ROW)
unnamed: D49.2 (A), MX49.2 (ROW)
unnamed: D50.2 (A), MX50.2 (ROW)
unnamed: D51.2 (A), MX51.2 (ROW)
unnamed: D52.2 (A), MX52.2 (ROW)
unnamed: D53.2 (A), MX53.2 (ROW)
unnamed: D54.2 (A), MX54.2 (ROW)
unnamed: D55.2 (A), MX55.2 (ROW)
unnamed: D56.2 (A), MX56.2 (ROW)
unnamed: D57.2 (A), MX57.2 (ROW)
unnamed: D58.2 (A), MX58.2 (ROW)
unnamed: D59.2 (A), MX59.2 (ROW)
unnamed: D60.2 (A), MX60.2 (ROW)
unnamed: D61.2 (A), MX61.2 (ROW)
unnamed: D62.2 (A), MX62.2 (ROW)
unnamed: D63.2 (A), MX63.2 (ROW)
unnamed: D64.2 (A), MX64.2 (ROW)
unnamed: D65.2 (A), MX65.2 (ROW)
unnamed: D66.2 (A), MX66.2 (ROW)
unnamed: D67.2 (A), MX67.2 (ROW)
unnamed: D68.2 (A), MX68.2 (ROW)
unnamed: D69.2 (A), MX69.2 (ROW)
unnamed: D70.2 (A), MX70.2 (ROW)
unnamed: D71.2 (A), MX71.2 (ROW)
unnamed: D72.2 (A), MX72.2 (ROW)
unnamed: D73.2 (A), MX73.2 (ROW)
unnamed: D74.2 (A), MX74.2 (ROW)
unnamed: D75.2 (A), MX75.2 (ROW)
unnamed: D76.2 (A), MX76.2 (ROW)
unnamed: D77.2 (A), MX77.2 (ROW)
unnamed: D78.2 (A), MX78.2 (ROW)
unnamed: D79.2 (A), MX79.2 (ROW)
unnamed: D80.2 (A), MX80.2 (ROW)
unnamed: D81.2 (A), MX81.2 (ROW)
unnamed: D82.2 (A), MX82.2 (ROW)
unnamed: D83.2 (A), MX83.2 (ROW)
unnamed: D84.2 (A), MX84.2 (ROW)
unnamed: D85.2 (A), MX85.2 (ROW)
unnamed: D86.2 (A), MX86.2 (ROW)
unnamed: D87.2 (A), MX87.2 (ROW)
unnamed: D88.2 (A), MX88.2 (ROW)
unnamed: D89.2 (A), MX89.2 (ROW)
unnamed: D90.2 (A), MX90.2 (ROW)
unnamed: D91.2 (A), MX91.2 (ROW)
unnamed: D92.2 (A), MX92.2 (ROW)
unnamed: D93.2 (A), MX93.2 (ROW)
unnamed: D94.2 (A), MX94.2 (ROW)
unnamed: D95.2 (A), MX95.2 (ROW)
unnamed: D96.2 (A), MX96.2 (ROW)
unnamed: D97.2 (A), MX97.2 (ROW)
unnamed: D98.2 (A), MX98.2 (ROW)
col00: MX1.1 (COL), MX19.1 (COL), MX37.1 (COL), MX55.1 (COL), MX72.1 (COL), MX89.1 (COL)
col01: MX2.1 (COL), MX20.1 (COL), MX38.1 (COL), MX56.1 (COL), MX73.1 (COL), MX90.1 (COL)
col02: MX3.1 (COL), MX21.1 (COL), MX39.1 (COL), MX57.1 (COL), MX74.1 (COL), MX91.1 (COL)
col03: MX4.1 (COL), MX22.1 (COL), MX40.1 (COL), MX58.1 (COL), MX75.1 (COL)
col04: MX5.1 (COL), MX23.1 (COL), MX41.1 (COL), MX59.1 (COL), MX76.1 (COL)
col05: MX6.1 (COL), MX24.1 (COL), MX42.1 (COL), MX60.1 (COL), MX77.1 (COL), MX92.1 (COL)
col06: MX7.1 (COL), MX25.1 (COL), MX43.1 (COL), MX61.1 (COL), MX78.1 (COL)
col07: MX8.1 (COL), MX26.1 (COL), MX44.1 (COL), MX62.1 (COL), MX79.1 (COL)
col08: MX9.1 (COL), MX27.1 (COL), MX45.1 (COL), MX63.1 (COL), MX80.1 (COL)
col09: MX10.1 (COL), MX28.1 (COL), MX46.1 (COL), MX64.1 (COL), MX81.1 (COL), MX93.1 (COL)
col10: MX11.1 (COL), MX29.1 (COL), MX47.1 (COL), MX65.1 (COL), MX82.1 (COL), MX94.1 (COL)
col11: MX12.1 (COL), MX30.1 (COL), MX48.1 (COL), MX66.1 (COL), MX83.1 (COL), MX95.1 (COL)
col12: MX13.1 (COL), MX31.1 (COL), MX49.1 (COL)
col13: MX14.1 (COL), MX32.1 (COL), MX50.1 (COL), MX67.1 (COL), MX84.1 (COL), MX96.1 (COL)
col14: MX15.1 (COL), MX33.1 (COL), MX51.1 (COL), MX68.1 (COL), MX85.1 (COL), MX97.1 (COL)
col15: MX16.1 (COL), MX34.1 (COL), MX52.1 (COL), MX69.1 (COL), MX86.1 (COL)
col16: MX17.1 (COL), MX35.1 (COL), MX53.1 (COL), MX70.1 (COL), MX87.1 (COL), MX98.1 (COL)
col17: MX18.1 (COL), MX36.1 (COL), MX54.1 (COL), MX71.1 (COL), MX88.1 (COL)
row0: D1.1 (K), D2.1 (K), D3.1 (K), D4.1 (K), D5.1 (K), D6.1 (K), D7.1 (K), D8.1 (K), D9.1 (K), D10.1 (K), D11.1 (K), D12.1 (K), D13.1 (K), D14.1 (K), D15.1 (K), D16.1 (K), D17.1 (K), D18.1 (K)
row1: D19.1 (K), D20.1 (K), D21.1 (K), D22.1 (K), D23.1 (K), D24.1 (K), D25.1 (K), D26.1 (K), D27.1 (K), D28.1 (K), D29.1 (K), D30.1 (K), D31.1 (K), D32.1 (K), D33.1 (K), D34.1 (K), D35.1 (K), D36.1 (K)
row2: D37.1 (K), D38.1 (K), D39.1 (K), D40.1 (K), D41.1 (K), D42.1 (K), D43.1 (K), D44.1 (K), D45.1 (K), D46.1 (K), D47.1 (K), D48.1 (K), D49.1 (K), D50.1 (K), D51.1 (K), D52.1 (K), D53.1 (K), D54.1 (K)
row3: D55.1 (K), D56.1 (K), D57.1 (K), D58.1 (K), D59.1 (K), D60.1 (K), D61.1 (K), D62.1 (K), D63.1 (K), D64.1 (K), D65.1 (K), D66.1 (K), D67.1 (K), D68.1 (K), D69.1 (K), D70.1 (K), D71.1 (K)
row4: D72.1 (K), D73.1 (K), D74.1 (K), D75.1 (K), D76.1 (K), D77.1 (K), D78.1 (K), D79.1 (K), D80.1 (K), D81.1 (K), D82.1 (K), D83.1 (K), D84.1 (K), D85.1 (K), D86.1 (K), D87.1 (K), D88.1 (K)
row5: D89.1 (K), D90.1 (K), D91.1 (K), D92.1 (K), D93.1 (K), D94.1 (K), D95.1 (K), D96.1 (K), D97.1 (K), D98.1 (K)

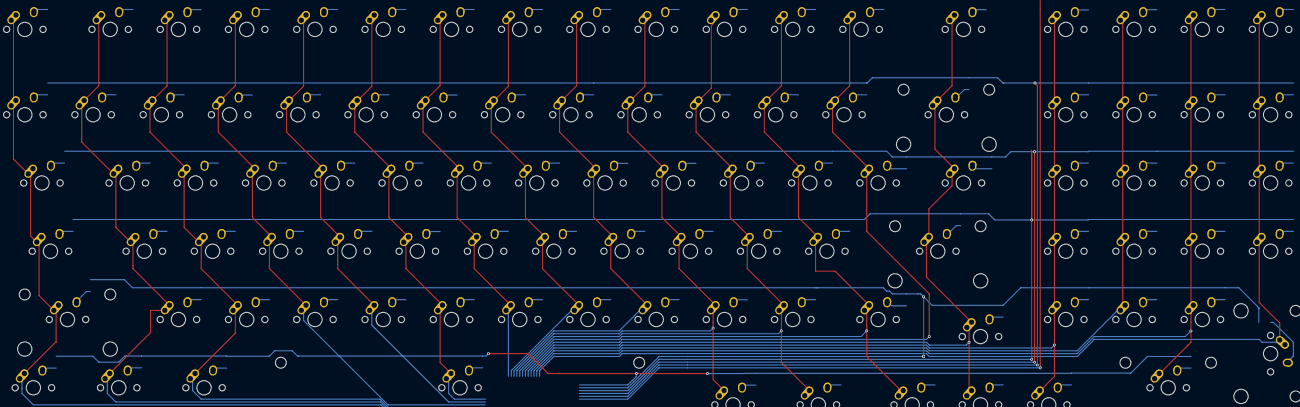
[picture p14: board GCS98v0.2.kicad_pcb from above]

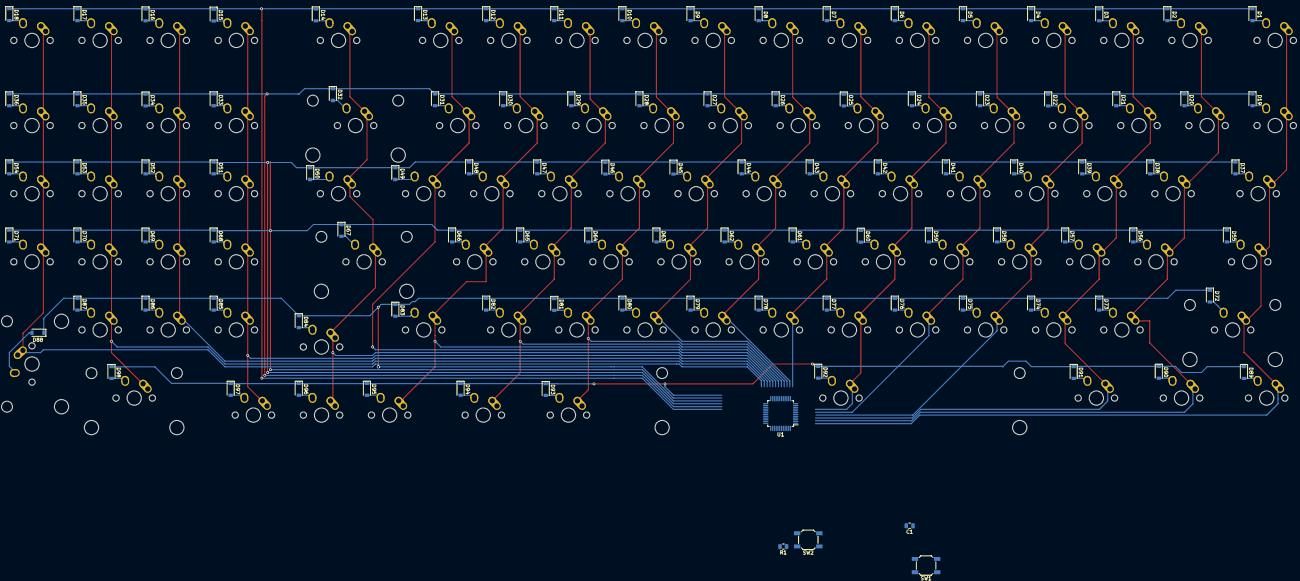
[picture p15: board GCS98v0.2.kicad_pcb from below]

Board: 2 copper layers, 201 parts (103 on the bottom side), 127 nets.

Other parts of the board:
C1: 100nF; C_0805_2012Metric
R1: 10K; R_0805_2012Metric
SW1: SW_Push; SW_SPST_SKQG_WithStem
SW2: SW_Push_SPDT; SW_SPST_SKQG_WithStem

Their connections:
+5V: C1.1; also elsewhere on the board
GND: SW1.1, SW2.1; also elsewhere on the board
unnamed 2: C1.2, SW1.2; also elsewhere on the board
unnamed 103: R1.1; also elsewhere on the board
unnamed: R1.2, SW2.2

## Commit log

2021-07-25 preliminary layout/matrix design
    [modified_1800_v1 switch matrix.xlsx, modified_1800_v1.dxf]
2021-07-25 add switch datasheets, general libraries, and Proton C library
2021-07-25 add libraries to kicad project
    [GCS98v1.kicad_pcb, GCS98v1.sch]
2021-07-25 matrix schematic made
    [matrix.sch, modified_1800_v1 switch matrix.xlsx]
2021-07-25 footprint assignments
    Proton C didn't have a footprint available, will need to create a footprint with pin array
    [GCS98v1.sch, matrix.sch, modified_1800_v1 switch matrix.xlsx]
2021-07-25 USB-C daughter board libraries added
2021-07-25 project 2 progress save
    Proton C seems to be out of stock everywhere, was gonna make this v2 anyway
    [GCS98 switch matrix.xlsx, GCS98.dxf, GCS98v2.kicad_pcb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]
2021-07-25 switch and diode layout done
    [GCS98v2.sch, matrix.sch]
2021-07-26 project corrupted
    system event viewer: "The description for Event ID 1 from source NVIDIA OpenGL Driver cannot be found. Either the component that raises this event is not installed on your local computer or the insta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
    rolling back to previous commit after submitting this one
2021-07-26 Revert "project corrupted"
    This reverts commit 6e2c007335474fac45b2d4a7722601066718bb04.
    [GCS98v2.kicad_pcb]
2021-07-26 columns routed
    updating graphics driver fixed the corruption issue
    [GCS98v2.kicad_pcb]
2021-07-26 column traces inverted to back copper
    [GCS98v2.kicad_pcb]
2021-07-26 rows and columns fully routed to spacebar area
    [GCS98v2.kicad_pcb]
2021-07-26 added TODO for when I pick this back up
    signing off for the night
    [GCS98v2.kicad_pcb]
2021-07-27 just overlay the footprints 4head
    did some digging into switch footprint that can accept many switch types, main ones are Cherry, ALPS, and Kailh low profile. These three encompass most commercially available switches
    [GCS98v2.kicad_pcb]
2021-07-28 check-in for someone to review schematic
    finally understand the reference schematic for the discovery board and basically just copied it, plus some housekeeping changes
    [GCS98v0.1.kicad_pcb, GCS98v0.1.sch, GCS98v0.2.kicad_pcb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]
2021-07-28 started v1
    MCU schematic 90%-100% done, still trying to figure out how to organize matrix
    [GCS98v1.kicad_pcb, GCS98v1.sch, matrix.sch]
2021-07-29 Unit A and Unit B btw :)
    tried to finish matrix schematic but the fucking custom symbol is dogshit
    [GCS98v1.sch, matrix.sch]
2021-07-29 fixed switches in matrix, ready for layout
    [GCS98v0.1.kicad_pcb, GCS98v0.1.sch, GCS98v0.2.kicad_pcb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]
2021-07-29 pick-and-place simulator
    [GCS98 switch matrix.xlsx, GCS98v1.kicad_pcb, matrix.sch]
2021-07-30 finished placing switches
    [GCS98 switch matrix.xlsx, GCS98v1.kicad_pcb, matrix.sch]
2021-07-30 tmp commit to revert
    [GCS98v1.kicad_pcb]
2021-07-30 Revert "tmp commit to revert"
    This reverts commit 719a65f32dae8c11ac86a2bec561b3681ac457b9.
    [GCS98v1.kicad_pcb]
2021-07-30 Revert "Revert "tmp commit to revert""
    This reverts commit c13e2767f99bd62ac667c42d9e0cd8f8c7ddee7e.
    [GCS98v1.kicad_pcb]
2021-07-30 i think i get my edge cuts back?
    all the revert commits I have done thus far is because layout editor crashes, and Event Viewer pointed to "NVIDIA OpenGL Driver" in each instance, and then both schematic and layout editors would crash when launching. Went to NVIDIA website to install the driver, selecting the option to perform a clean install in the wizard.
    PSA: the express installation option in the driver installer and GeForce Experience leave a lot of duplicate files for programs to find and incorrectly use, make sure to perform a clean install every time you update NVIDIA drivers
    [GCS98v1.kicad_pcb]
2021-07-30 RGB edition pick and place machine by Corsair
    [GCS98v1.kicad_pcb]
2021-07-30 matrix pick and place done, now to routing it
    [GCS98v1.kicad_pcb]
2021-07-30 backup before changing symbols
    realized the switch symbol I had been using actually has 4 pins, in two stacks of two (really fucking dumb)
    [GCS98v1.kicad_pcb]
2021-07-30 another backup before changing rgb symbol
    [GCS98v1.kicad_pcb, matrix.sch]
2021-07-30 matrix wiring 90% done
    still need to figure out how to get power to LEDs (probably route 5V through top plane, then fill in the rest of the top with ground; not much point to filling bottom plane with ground considering al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
    also need to get rows and columns into buses in the spacebar area, otherwise all that's left is min-maxing the positions of connector, MCU, VRM, resonator, and capacitors/resistors/diodes
    [GCS98v1.kicad_pcb, matrix.sch]
2021-08-19 preliminary work on USB hub
    The Texas Instruments USB hub that is currently in there seems like the ticket, but I am still not sure about how USB C connectors will work with the hub IC since it is only for USB 2.0. The main issue is that USB 3.0 and up natively support 3 different power delivery modes up to 15W (and USB power delivery supporting up to 100W), but this is higher than USB 2.0 capabilities and I don't want to fry the thing.
    [GCS98v1.sch, USB_hub.sch, matrix.sch]
2021-08-20 going to use two USB C Daughterboards
    after doing some research into connecting a USB C connector to the USB 2.0 hub, I looked at the KiCad project for the Daughterboard and saw that an overcurrent protection circuit, IC, and ferrite bea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
    [USB_hub.sch]
2021-08-28 redid matrix routing, not doing USB daughter board because of parts availability
    [GCS98v1.kicad_pcb, GCS98v1.sch, USB_hub.sch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]
